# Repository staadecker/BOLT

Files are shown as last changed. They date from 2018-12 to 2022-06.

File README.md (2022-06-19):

# BOLT

BOLT is a machine that measures your reaction speed. The machine has 64 buttons which contain embedded LEDs. When an LED turns on, the user must press the matching button. The machine then calculates the user's reaction speed based on the time it took the user to press the button.

The project has two components.
- `arduino` : The arduino code that controls the buttons and LED's
- `bolt-mobile` : The Flutter code that uses a phone to communicate with the Arduino and displays the results\

This project reached a semi-functionning state but was not fully finished.

### Bluetooth

To communicate the Arduino and phone send each other packets over bluetooth. The packets' format is defined in `bluetooth-protocol.md`.

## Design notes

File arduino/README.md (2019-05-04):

# Bolt Arduino

This folder contains the Arduino code for the BOLT project.

# Get started (with CLion)

1. Edit `CMakeLists.txt` to match your software setup.

2. Edit `lib/constants.h` to match your hardware setup.

3. Run the `upload-main` run configuration in CLion to upload the code.

4. Use the Serial Monitor plugin to monitor the Arduino serial.

# Implementation Details

## The Hardware Setup

The Arduino controls 64 buttons using a 64-button shield. It controls the LEDs using eight 8-bit shift registers. It communicates to a bluetooth device with an external bluetooth chip.

## The Code

The code that runs on the Arduino controls the LED's and registers the button presses. It also allows a device to connect via bluetooth. This device will be informed of button presses and will be able to send commands to turn the LEDs on or off.

### Arduino states (modes)

1. **Start state.** The board is either waiting for the user to switch to the offline state by pressing the middle button (#0) or the online state (switched to when a bluetooth packet is received).

2. **Offline state.** The state is a simple game that measures the users reaction speed.

3. **Online mode.** In this state, the arduino simply acts as a bridge between the buttons/LEDs and the phone. The Arduino is listening for bluetooth commands sent from the phone.

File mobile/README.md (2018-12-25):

This repository contains the mobile code for the BOLT project.
This mobile app uses flutter.

## The code

When complete, the mobile app will be able to control the game by deciding when to turn on and off the LEDs. It will then display the average reaction time speed for the user.

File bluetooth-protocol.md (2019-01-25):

# Bluetooth protocol

This protocol dictates how the information being sent between the Arduino and the phone should be formatted.

## Packet Format

Packet's data is sent using ASCII. The maximum length of a packet is 255 bytes.

Packets start with ASCII byte 1 (start of header) and end with ASCII byte 4 (end of transmission).

After the ASCII byte 1, a series of commands is sent. Each command has a command byte and optionnally an argument. There may be multiple commands in one packet.

Each packet should be acknowledged by the receiver by replying with an ASCII byte 6 (acknowledged).

### Example transmission
Phone sends `0x01` + `L30S` + `0x03`. This turns on led number 30 and then shifts out to make the result appear.

Arduino replies with `0x06`.

### Arduino to Phone Commands

| Command byte | Hexadecimal | Decimal | Name | Description | Argument description |
|---|---|---|---|---|---|
| P | 0x50 | 80 | Button pressed | Called when a button is pressed | Number of the button pressed (between 0-63)|

### Phone to Arduino Commands

| Command byte | Hexadecimal | Decimal | Name | Description | Argument description |
|---|---|---|---|---|---|
| B | 0x42 | 66 | Begin | Called to start online game | None |
| E | 0x45 | 69 | End | Called to end online game | None |
| I | 0x49 | 73 | Led OFF | Called to turn off led | Number of LED to turn off (between 0-63)|
| O | 0x4F | 79 | Led ON | Called to turn on led | Number of LED to turn on (between 0-63)|
| S | 0x53 | 83 | Shift out | Called to actually display changes with led on/off | None |

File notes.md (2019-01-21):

# LED Wiring

[Shift register datasheet](http://www.ti.com/lit/ds/symlink/sn74hc595.pdf). [Arduino tutorial for shift registers](https://www.arduino.cc/en/tutorial/ShiftOut).

Clock = SCK. Latch = RCK. Data = SER. 

VCC is connected to an output pin that allows `analogWrite` (PWM).

Check [`bolt-arduino/constants.h`](bolt-arduino/constants.h) to find what pins to use on the Arduino.

# Flashing new firware onto fake HM-10

Follow [this tutorial](https://blog.yavilevich.com/2018/04/should-you-throw-away-your-cc41-hm-10-clones-now-that-android-8-is-here/).

# Setting up CLion 

Make sure to update CMakeLists.txt for your OS.

## For Windows

Use the official distribution of MinGW as the toolchain. See [here](http://mingw.org/wiki/Getting_Started). Install with GUI and then install gcc-core, gcc-g++ and Make.

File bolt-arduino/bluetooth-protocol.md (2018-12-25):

# Bluetooth protocol

## Arduino states

| State | When | What | Enter state | Leave state |
|---|---|---|---|---|
| Online | While playing an online game | Device is only listensing for bluetooth packets | Receive a START packet | Receive and END packet <br> OR <br> Connection Lost (incomplete packet/no acknowledge) |
| Ready | When user is not playing a game | Device is listening for bluetooth packets | Game ends | Game starts (online or offline) |
| Offline | When user is playing an offline game | Device is not listening for packets | Offline game started (middle button pressed) | Offline game ends |

## Packet Format

Everything in ASCII

Outgoing packet : Start of text (ASCII 2) + Command byte + argument + End of text (ASCII 3)

Receive : Acknowledge (ASCII 6)

### Example
`0x02` + `L30` + `0x03` turns on led number 30. Replies with `0x06`

## Commands
### Arduino to Phone

| Command byte | Hexadecimal | Decimal | Name | Description | Argument |
|---|---|---|---|---|---|
| P | 0x50 | 80 | Button pressed | Called when a button is pressed | Number of the button pressed (between 0-63)|

### Phone to Arduino

| Command byte | Hexadecimal | Decimal | Name | Description | Argument |
|---|---|---|---|---|---|
| B | 0x42 | 66 | Begin | Called to start online game | None |
| E | 0x45 | 69 | End | Called to end online game | None |
| I | 0x49 | 73 | Led OFF | Called to turn off led | Number of LED to turn off (between 0-63)|
| O | 0x4F | 79 | Led ON | Called to turn on led | Number of LED to turn on (between 0-63)|
| S | 0x53 | 83 | Shift out | Called to actually display changes with led on/off | None |

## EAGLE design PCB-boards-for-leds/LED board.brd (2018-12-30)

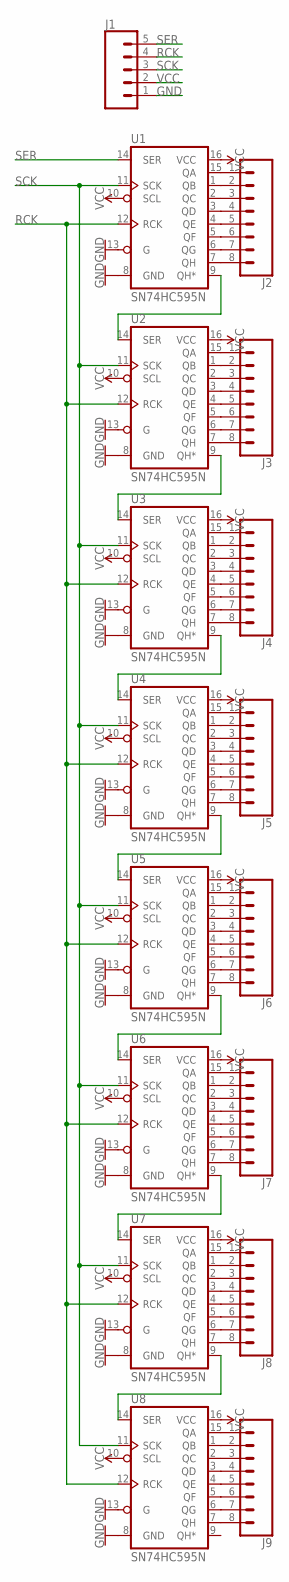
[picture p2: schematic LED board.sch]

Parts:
J1: CONN_05; 1X05
J2, J3, J4, J5, J6, J7, J8, J9: CONN_08"; 1X08
U1, U2, U3, U4, U5, U6, U7, U8: SN74HC595N; DIP16

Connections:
GND: J1.1, U1.8 (GND), U1.13 (G), U2.8 (GND), U2.13 (G), U3.8 (GND), U3.13 (G), U4.8 (GND), U4.13 (G), U5.8 (GND), U5.13 (G), U6.8 (GND), U6.13 (G), U7.8 (GND), U7.13 (G), U8.8 (GND), U8.13 (G)
unnamed: U1.9 (QH*), U2.14 (SER)
unnamed: U2.9 (QH*), U3.14 (SER)
unnamed: U3.9 (QH*), U4.14 (SER)
unnamed: U4.9 (QH*), U5.14 (SER)
unnamed: U5.9 (QH*), U6.14 (SER)
unnamed: U6.9 (QH*), U7.14 (SER)
unnamed: U7.9 (QH*), U8.14 (SER)
unnamed: J2.1, U1.15 (QA)
unnamed: J2.2, U1.1 (QB)
unnamed: J2.3, U1.2 (QC)
unnamed: J2.4, U1.3 (QD)
unnamed: J2.5, U1.4 (QE)
unnamed: J2.6, U1.5 (QF)
unnamed: J2.7, U1.6 (QG)
unnamed: J2.8, U1.7 (QH)
unnamed: J3.1, U2.15 (QA)
unnamed: J3.2, U2.1 (QB)
unnamed: J3.3, U2.2 (QC)
unnamed: J3.4, U2.3 (QD)
unnamed: J3.5, U2.4 (QE)
unnamed: J3.6, U2.5 (QF)
unnamed: J3.7, U2.6 (QG)
unnamed: J3.8, U2.7 (QH)
unnamed: J4.1, U3.15 (QA)
unnamed: J4.2, U3.1 (QB)
unnamed: J4.3, U3.2 (QC)
unnamed: J4.4, U3.3 (QD)
unnamed: J4.5, U3.4 (QE)
unnamed: J4.6, U3.5 (QF)
unnamed: J4.7, U3.6 (QG)
unnamed: J4.8, U3.7 (QH)
unnamed: J5.1, U4.15 (QA)
unnamed: J5.2, U4.1 (QB)
unnamed: J5.3, U4.2 (QC)
unnamed: J5.4, U4.3 (QD)
unnamed: J5.5, U4.4 (QE)
unnamed: J5.6, U4.5 (QF)
unnamed: J5.7, U4.6 (QG)
unnamed: J5.8, U4.7 (QH)
unnamed: J6.1, U5.15 (QA)
unnamed: J6.2, U5.1 (QB)
unnamed: J6.3, U5.2 (QC)
unnamed: J6.4, U5.3 (QD)
unnamed: J6.5, U5.4 (QE)
unnamed: J6.6, U5.5 (QF)
unnamed: J6.7, U5.6 (QG)
unnamed: J6.8, U5.7 (QH)
unnamed: J7.1, U6.15 (QA)
unnamed: J7.2, U6.1 (QB)
unnamed: J7.3, U6.2 (QC)
unnamed: J7.4, U6.3 (QD)
unnamed: J7.5, U6.4 (QE)
unnamed: J7.6, U6.5 (QF)
unnamed: J7.7, U6.6 (QG)
unnamed: J7.8, U6.7 (QH)
unnamed: J8.1, U7.15 (QA)
unnamed: J8.2, U7.1 (QB)
unnamed: J8.3, U7.2 (QC)
unnamed: J8.4, U7.3 (QD)
unnamed: J8.5, U7.4 (QE)
unnamed: J8.6, U7.5 (QF)
unnamed: J8.7, U7.6 (QG)
unnamed: J8.8, U7.7 (QH)
unnamed: J9.1, U8.15 (QA)
unnamed: J9.2, U8.1 (QB)
unnamed: J9.3, U8.2 (QC)
unnamed: J9.4, U8.3 (QD)
unnamed: J9.5, U8.4 (QE)
unnamed: J9.6, U8.5 (QF)
unnamed: J9.7, U8.6 (QG)
unnamed: J9.8, U8.7 (QH)
RCK: J1.4, U1.12 (RCK), U2.12 (RCK), U3.12 (RCK), U4.12 (RCK), U5.12 (RCK), U6.12 (RCK), U7.12 (RCK), U8.12 (RCK)
SCK: J1.3, U1.11 (SCK), U2.11 (SCK), U3.11 (SCK), U4.11 (SCK), U5.11 (SCK), U6.11 (SCK), U7.11 (SCK), U8.11 (SCK)
SER: J1.5, U1.14 (SER)
VCC: J1.2, U1.10 (SCL), U1.16 (VCC), U2.10 (SCL), U2.16 (VCC), U3.10 (SCL), U3.16 (VCC), U4.10 (SCL), U4.16 (VCC), U5.10 (SCL), U5.16 (VCC), U6.10 (SCL), U6.16 (VCC), U7.10 (SCL), U7.16 (VCC), U8.10 (SCL), U8.16 (VCC)

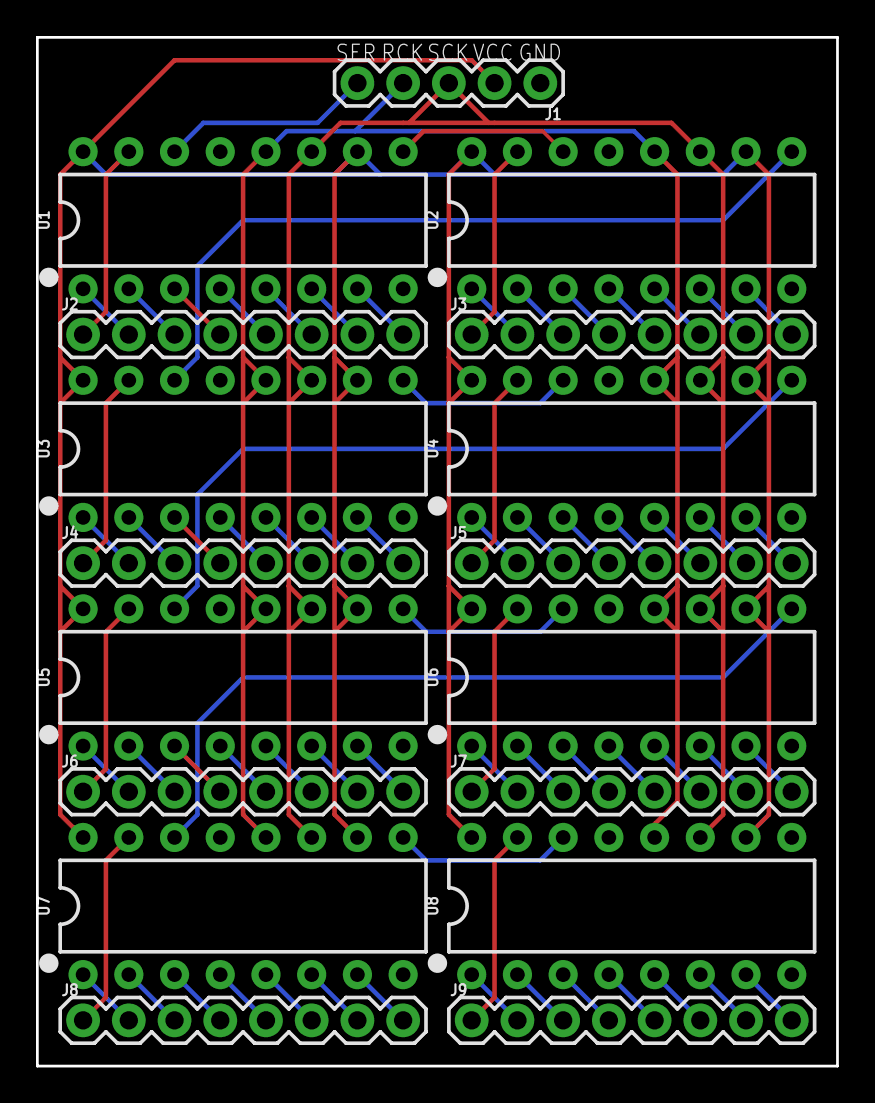
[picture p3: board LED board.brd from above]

Board: 2 copper layers, 44.4 x 57.1 mm, 17 parts (0 on the bottom side), 76 nets.

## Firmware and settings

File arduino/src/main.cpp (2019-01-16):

#include "lib/game.h"
#include "lib/main.h"
#include "lib/bluetooth.h"
#include "lib/button.h"
#include "lib/led.h"
#include "lib/logger.h"
#include "lib/screen.h"
#include "lib/flasher.h"
#include <Arduino.h>

void startReadyMode() {
  button::clearLast();
  screen::display("READY");
  flasher::startFlashing(0);
}

// Makes chasing lights on the outer circle
void bootUpSequence() {
  for (int i = 32; i < 64; i++) {
    led::turnOn(i);
    led::shiftOut();
    delay(70);
    led::turnOff(i);
  }

  for (int i = 0; i < 64; i++) {
    led::turnOff(i);
  }
  led::shiftOut();
}

void setup() {
  //Generate new random seed such that button sequence is different each time
  randomSeed(analogRead(0));

  //Setup
  bluetooth::setup();
  button::setup();
  led::setup();
  logger::log(logger::TYPE_INFO, "main", "Setup done");

  bootUpSequence();

  if (not bluetooth::shouldGoOnline()) {
    startReadyMode(); //Unless already connected start ready mode
  }

  while (true) {
    //If connected to bluetooth go in online mode
    if (bluetooth::shouldGoOnline()) {
      flasher::stopFlashing(0);
      screen::display("ONLINE");

      bluetooth::listen();

      //When disconnected
      startReadyMode();
    }

    //If middle button pressed go in offline mode
    if (button::isPressed(0)) {
      flasher::stopFlashing(0);

      game::start();

      //When game ends
      startReadyMode();
    }

    flasher::checkFlash(); // Will flash if should flash
  }

}

void loop(){}

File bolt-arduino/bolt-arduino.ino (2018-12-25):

#include "button.h"
#include "led.h"
#include "screen.h"
#include "game.h"
#include "timer.h"
#include "constants.h"
#include "flasher.h"
#include "logger.h"
#include "bluetooth.h"


void setup() {
  Serial.begin(9600);

  //Generate new random seed
  randomSeed(analogRead(0));

  //Setup
  bluetooth::setup();
  button::setup();
  led::setup();
  logger::log(logger::TYPE_INFO, "main", "Setup done");

  if (not bluetooth::shouldGoOnline()) {
    startReadyMode(); //Unless already connected start ready mode
  }
}


void loop() {
  //If connected to bluetooth go in online mode
  if (bluetooth::shouldGoOnline()) {
    flasher::stopFlashing(0);
    screen::display("ONLINE");

    bluetooth::listen();

    startReadyMode();
  }

  //If middle button pressed go in offline mode
  if (button::isPressed(0)) {
    flasher::stopFlashing(0);

    game::start();

    startReadyMode();
  }

  flasher::checkFlash(); // Will flash if should flash
}

void startReadyMode() {
  button::clearLast();
  screen::display("READY");
  flasher::startFlashing(0);
}

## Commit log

2017-09-03 Framework for basic stand alone game. No hardware interaction except for buttons.
2017-09-03 Renamed main file to follow arduino project structure rules
2017-09-07 Added constants file and simplfied button.h
2017-09-07 Refatored clock thread. Updated to new naming convention
2017-09-07 Added thread controller
2017-09-07 Added modes to clock thread
2017-09-11 Add missing import to main .ino file
    [bolt-arduino.ino]
2017-09-11 Change default timer time to 0.
2017-09-11 Add button_isPressed in button.h for custom while loops
2017-09-13 Unfinished work on led class and shift out function
2017-09-13 Finish basic led.h class - no flashing
2017-09-13 Change button index system to start at 0
2017-09-13 Run auto format in arduino ide
2017-09-14 Support for flashing leds
2017-09-26 Fix bug in led shift out loop
    [led.cpp]
2017-09-27 Low voltage shift out - working
2017-09-27 Working 5V led
2017-09-27 Working Low voltage shift out
2017-09-27 Working array for led states
2017-09-27 Working flasher, thread always running
2017-09-27 Working flasher, with thread disabled mode
2017-09-27 Fixed logic for failing to add thread to control
2017-09-27 Change flashing button to 0 from 1
2017-09-27 Fix pin values
2017-09-27 Add option for testing without button shield and screen
2017-10-11 Simplify function names (no longer avoid key names)
    [bolt-arduino.ino, led.cpp]
2017-10-12 change pin const
2017-10-13 Refactor flashing and led system
2017-10-15 Make button turn off after time ends
2017-10-16 Remove threads
2017-10-16 Add clear button press method
2017-10-17 Remove format millis method
2017-10-17 Seperate shiftout from led on/off
2017-10-20 Fix bug where button is called twice - untested
2017-11-07 Change print to write for bluetooth
2018-07-25 Now able to connect to device
2018-09-08 Working count down triggered by button press
2018-12-25 Moved bolt-mobile files to subfolder
2018-12-30 Added led tester and refactored main code into sub-directory
2018-12-30 Added test for button press
2018-12-30 Add test to test buttons with LEDs
2018-12-30 Prepare for switch for bluetooth
2018-12-30 Add PCB board design
    [LED board.brd, LED board.sch]
2019-01-16 Moved directories around
    [LED board.brd, LED board.sch]
2019-01-16 Moved Arduino files around
2019-01-19 Use classes for buttons and games
2019-01-19 Move led and bluetooth to classes
2019-01-19 Made interface above button manager
2019-01-20 Working debug button press
2019-01-21 Fixed tests. Remove unnecessary arguments in Main,startReadyMode.
    [main.cpp, tests.cpp]
2019-01-23 Fixed crashing issue (caused by global pointer pointing to local variable).
    [main.cpp]
2019-01-24 Switch to threader model with working code
2019-01-25 Rename bolt-mobile folder to just mobile
2019-01-31 Add comment for making wiring
2019-05-04 Fixed bug where number of buttons pressed is not reset after an offline game
2019-05-04 Make changes to button shield work for multiple button presses.

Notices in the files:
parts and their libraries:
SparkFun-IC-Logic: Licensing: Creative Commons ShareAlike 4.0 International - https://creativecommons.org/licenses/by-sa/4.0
